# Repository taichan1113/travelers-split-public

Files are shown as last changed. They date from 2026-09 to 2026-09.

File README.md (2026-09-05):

[日本語](#日本語) / [English](#english)

# Travelers Split Public

## English

Public KiCad release bundle for the Travelers Split keyboard hardware.

### Projects

- `split_L_v2/ULP_Keyboard_split_L.kicad_pro`
- `split_R_v2/ULP_Keyboard_split_R.kicad_pro`
- `split_prog/ULP_Keyboard_split_prog.kicad_pro`

### Libraries

Project-local KiCad tables reference the bundled libraries under `libraries/` via `${KIPRJMOD}/../libraries/...`, so the projects can be opened without setting `KICAD_USER_LOCAL`.

### Repository Layout

- `split_L_v2/`: left half KiCad project
- `split_R_v2/`: right half KiCad project
- `split_prog/`: programmer KiCad project
- `libraries/`: symbols, footprints, and 3D models used by the projects

## 日本語

Travelers Split keyboard hardware の公開用 KiCad リリース一式です。

### プロジェクト

- `split_L_v2/ULP_Keyboard_split_L.kicad_pro`
- `split_R_v2/ULP_Keyboard_split_R.kicad_pro`
- `split_prog/ULP_Keyboard_split_prog.kicad_pro`

### ライブラリ

各プロジェクト内の KiCad ライブラリテーブルは、同梱の `libraries/` を `${KIPRJMOD}/../libraries/...` として参照します。そのため、`KICAD_USER_LOCAL` を設定しなくてもプロジェクトを開けます。

### リポジトリ構成

- `split_L_v2/`: 左手側の KiCad プロジェクト
- `split_R_v2/`: 右手側の KiCad プロジェクト
- `split_prog/`: 書き込み器用の KiCad プロジェクト
- `libraries/`: 各プロジェクトで使用するシンボル、フットプリント、3Dモデル

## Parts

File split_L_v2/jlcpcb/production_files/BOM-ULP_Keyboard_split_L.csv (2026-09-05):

Comment | Designator | Footprint | LCSC | Quantity
0.1uF | C3,C5 | C_0603_1608Metric_Pad1.08x0.95mm_HandSolder | C14663 | 2
10uF | C1 | C_0603_1608Metric_Pad1.08x0.95mm_HandSolder | C19702 | 1
1M | R1,R3 | R_0603_1608Metric_Pad0.98x0.95mm_HandSolder | C22935 | 2
D | D00,D01,D02,D03,D04,D05,D10,D11,D12,D13,D14,D15,D20,D21,D22,D23,D24,D25,D30,D34,D35 | Nexperia_CFP3_SOD-123W | C81598 | 21

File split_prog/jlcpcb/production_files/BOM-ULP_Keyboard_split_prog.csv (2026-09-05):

Comment | Designator | Footprint | LCSC | Quantity
1uF X5R | C2,C4 | C_0603_1608Metric_Pad1.08x0.95mm_HandSolder | C19702 | 2
5.1k | R6,R7 | R_0603_1608Metric_Pad0.98x0.95mm_HandSolder | C23186 | 2
TLV75533PDBV | U1 | SOT-23-5 | C404027 | 1
USBLC6-2SC6 | D7 | SOT-23-6 | C7519 | 1

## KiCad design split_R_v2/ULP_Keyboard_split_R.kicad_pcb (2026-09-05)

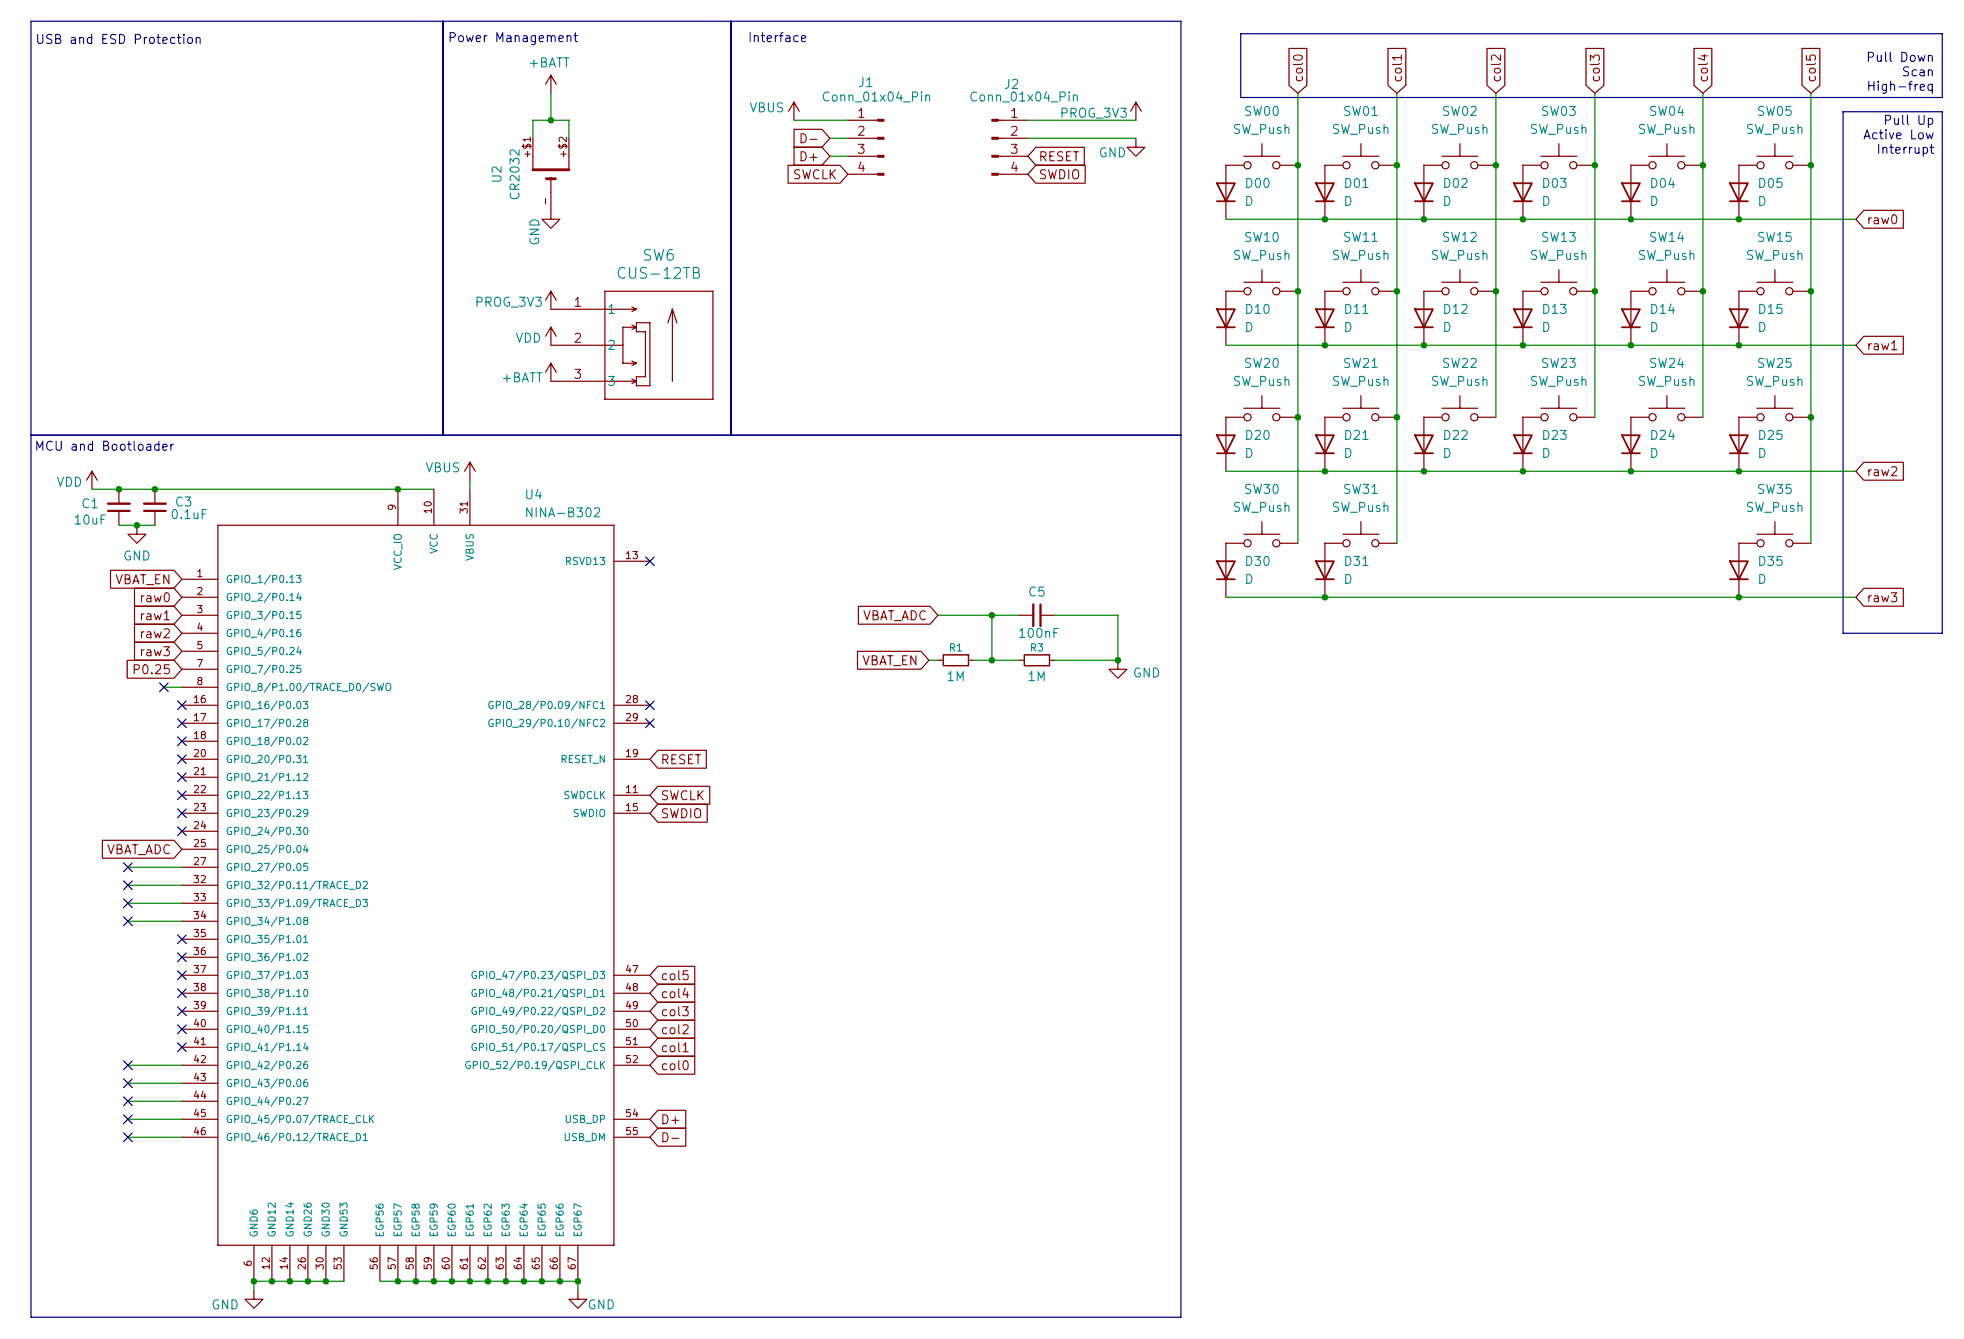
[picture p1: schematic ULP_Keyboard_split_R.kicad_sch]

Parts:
C1: 10uF; C_0603_1608Metric_Pad1.08x0.95mm_HandSolder; LCSC C19702
C3: 0.1uF; C_0603_1608Metric_Pad1.08x0.95mm_HandSolder; LCSC C14663
C5: 100nF; C_0603_1608Metric_Pad1.08x0.95mm_HandSolder; LCSC C14663
D00, D01, D02, D03, D04, D05, D10, D11, D12, D13, D14, D15, D20, D21, D22, D23, D24, D25, D30, D31, D35: D; Nexperia_CFP3_SOD-123W; LCSC C81598
J1, J2: Conn_01x04_Pin; ConnThrough_1x04
R1, R3: 1M; R_0603_1608Metric_Pad0.98x0.95mm_HandSolder; LCSC C22935
SW00, SW01, SW02, SW03, SW04, SW10, SW11, SW12, SW13, SW14, SW20, SW21, SW22, SW23, SW24, SW30, SW31: SW_Push; Kailh_socket_PG1316S_my_SMD
SW05, SW15, SW25, SW35: SW_Push; Kailh_socket_PG1316M_my_SMD
SW6: CUS-12TB; CUS12TB
U2: CR2032; CR2032-SMD-BH67D5
U4: NINA-B302; NINA_302_my; PART_DESCRIPTION Stand-alone Bluetooth low energy module

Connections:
+BATT: SW6.3, U2.+$1, U2.+$2
D+: J1.3, U4.54 (USB_DP)
D-: J1.2, U4.55 (USB_DM)
GND: C1.1, C3.1, C5.1, J2.2, R3.1, U2.-, U4.6 (GND6), U4.12 (GND12), U4.14 (GND14), U4.26 (GND26), U4.30 (GND30), U4.53 (GND53), U4.56 (EGP56), U4.57 (EGP57), U4.58 (EGP58), U4.59 (EGP59), U4.60 (EGP60), U4.61 (EGP61), U4.62 (EGP62), U4.63 (EGP63), U4.64 (EGP64), U4.65 (EGP65), U4.66 (EGP66), U4.67 (EGP67)
unnamed: D00.2 (A), SW00.1
unnamed: D01.2 (A), SW01.1
unnamed: D02.2 (A), SW02.1
unnamed: D03.2 (A), SW03.1
unnamed: D04.2 (A), SW04.1
unnamed: D05.2 (A), SW05.1
unnamed: D10.2 (A), SW10.1
unnamed: D11.2 (A), SW11.1
unnamed: D12.2 (A), SW12.1
unnamed: D13.2 (A), SW13.1
unnamed: D14.2 (A), SW14.1
unnamed: D15.2 (A), SW15.1
unnamed: D20.2 (A), SW20.1
unnamed: D21.2 (A), SW21.1
unnamed: D22.2 (A), SW22.1
unnamed: D23.2 (A), SW23.1
unnamed: D24.2 (A), SW24.1
unnamed: D25.2 (A), SW25.1
unnamed: D30.2 (A), SW30.1
unnamed: D31.2 (A), SW31.1
unnamed: D35.2 (A), SW35.1
P0.25: U4.7 (GPIO_7/P0.25)
PROG_3V3: J2.1, SW6.1
RESET: J2.3, U4.19 (RESET_N)
SWCLK: J1.4, U4.11 (SWDCLK)
SWDIO: J2.4, U4.15 (SWDIO)
VBAT_ADC: C5.2, R1.1, R3.2, U4.25 (GPIO_25/P0.04)
VBAT_EN: R1.2, U4.1 (GPIO_1/P0.13)
VBUS: J1.1, U4.31 (VBUS)
VDD: C1.2, C3.2, SW6.2, U4.9 (VCC_IO), U4.10 (VCC)
col0: SW00.2, SW10.2, SW20.2, SW30.2, U4.52 (GPIO_52/P0.19/QSPI_CLK)
col1: SW01.2, SW11.2, SW21.2, SW31.2, U4.51 (GPIO_51/P0.17/QSPI_CS)
col2: SW02.2, SW12.2, SW22.2, U4.50 (GPIO_50/P0.20/QSPI_D0)
col3: SW03.2, SW13.2, SW23.2, U4.49 (GPIO_49/P0.22/QSPI_D2)
col4: SW04.2, SW14.2, SW24.2, U4.48 (GPIO_48/P0.21/QSPI_D1)
col5: SW05.2, SW15.2, SW25.2, SW35.2, U4.47 (GPIO_47/P0.23/QSPI_D3)
raw0: D00.1 (K), D01.1 (K), D02.1 (K), D03.1 (K), D04.1 (K), D05.1 (K), U4.2 (GPIO_2/P0.14)
raw1: D10.1 (K), D11.1 (K), D12.1 (K), D13.1 (K), D14.1 (K), D15.1 (K), U4.3 (GPIO_3/P0.15)
raw2: D20.1 (K), D21.1 (K), D22.1 (K), D23.1 (K), D24.1 (K), D25.1 (K), U4.4 (GPIO_4/P0.16)
raw3: D30.1 (K), D31.1 (K), D35.1 (K), U4.5 (GPIO_5/P0.24)

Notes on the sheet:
Interface
MCU and Bootloader
Pull Down Scan High-freq
Power Management
Pull Up Active Low Interrupt
USB and ESD Protection

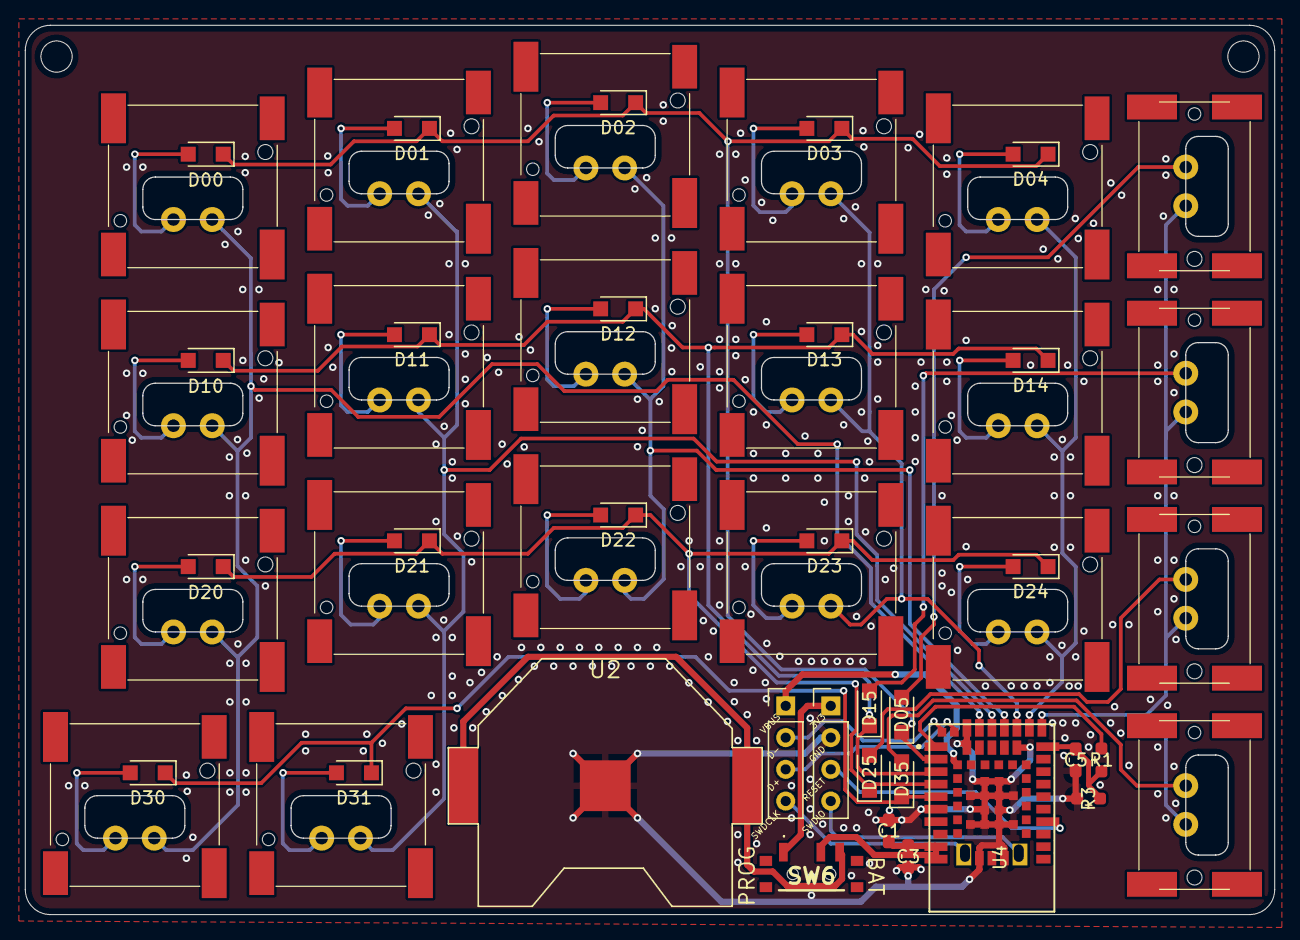
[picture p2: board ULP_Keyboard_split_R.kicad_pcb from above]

Board: 2 copper layers, 100.0 x 71.2 mm, 52 parts (0 on the bottom side), 43 nets.

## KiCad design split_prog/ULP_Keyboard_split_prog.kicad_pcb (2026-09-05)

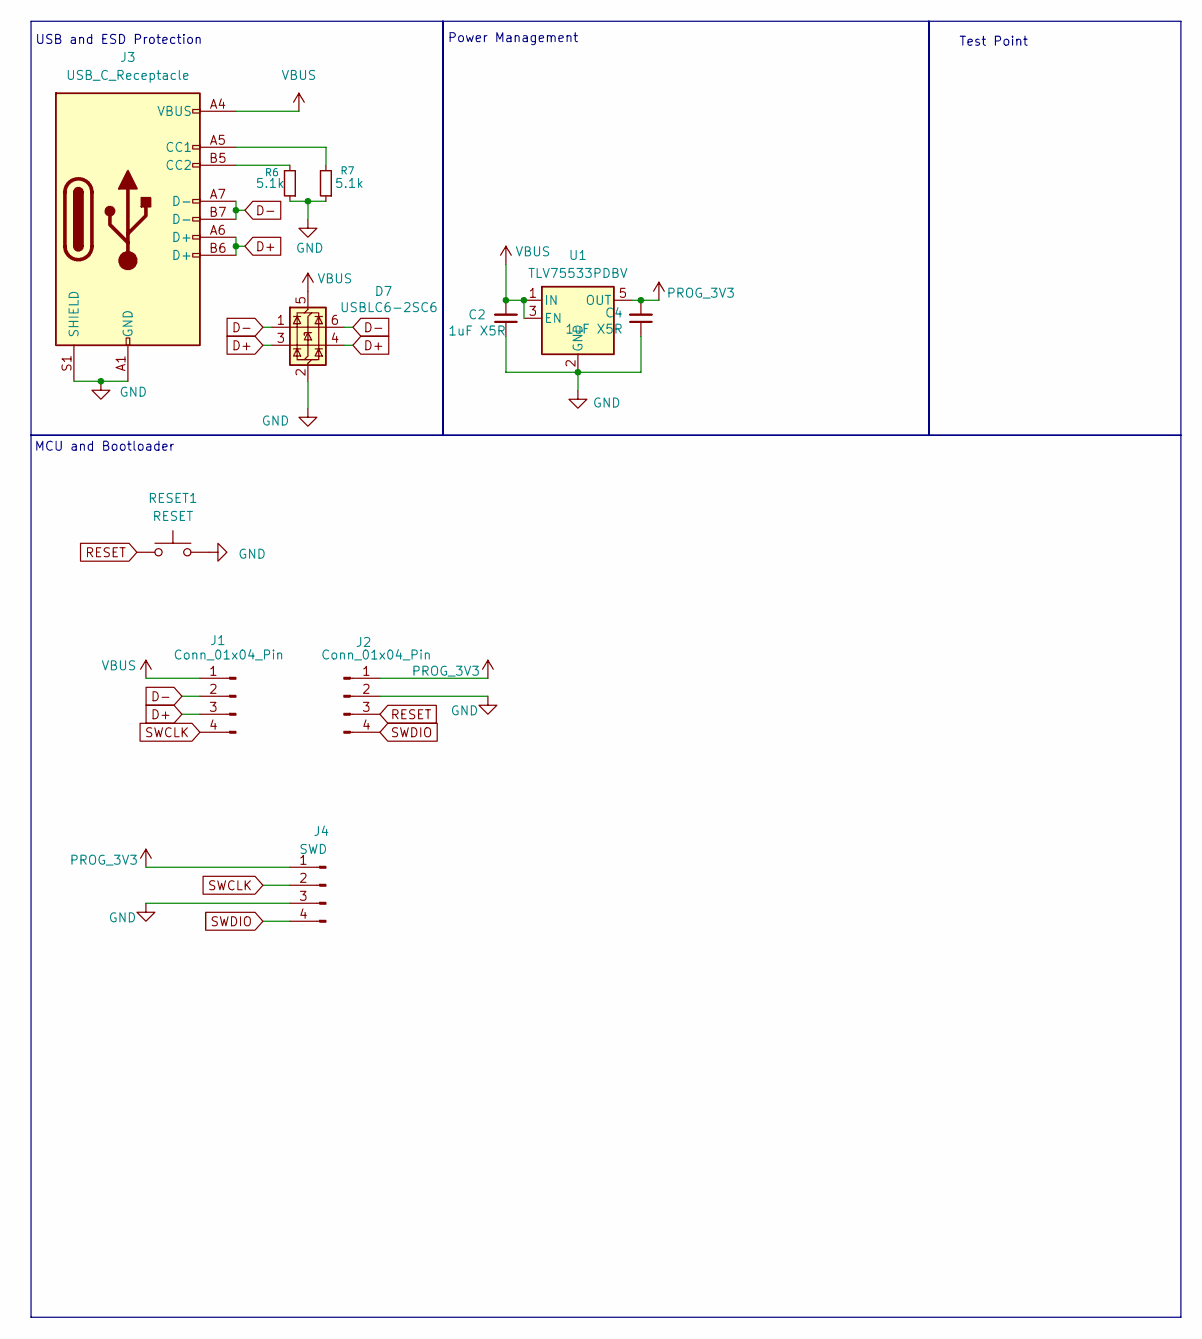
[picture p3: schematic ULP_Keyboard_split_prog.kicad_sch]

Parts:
C2, C4: 1uF X5R; C_0603_1608Metric_Pad1.08x0.95mm_HandSolder; LCSC C19702
D7: USBLC6-2SC6; SOT-23-6; LCSC C7519
J1, J2: Conn_01x04_Pin; ConnThrough_1x04
J3: USB_C_Receptacle; USB_C_Receptacle_HRO_TYPE-C-31-M-12
J4: SWD; JST_SH_BM04B-SRSS-TB_1x04-1MP_P1.00mm_Vertical
R6, R7: 5.1k; R_0603_1608Metric_Pad0.98x0.95mm_HandSolder; LCSC C23186
RESET1: RESET; SW_SPST_TL3342
U1: TLV75533PDBV; SOT-23-5; LCSC C404027

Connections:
D+: D7.3 (I/O2), D7.4 (I/O2), J1.3, J3.A6 (D+), J3.B6 (D+)
D-: D7.1 (I/O1), D7.6 (I/O1), J1.2, J3.A7 (D-), J3.B7 (D-)
GND: C2.1, C4.1, D7.2 (GND), J2.2, J3.A1 (GND), J3.A12 (GND), J3.B1 (GND), J3.B12 (GND), J3.S1 (SHIELD), J4.3, R6.1, R7.1, RESET1.2, U1.2 (GND)
unnamed: J3.A5 (CC1), R7.2
unnamed: J3.B5 (CC2), R6.2
PROG_3V3: C4.2, J2.1, J4.1, U1.5 (OUT)
RESET: J2.3, RESET1.1
SWCLK: J1.4, J4.2
SWDIO: J2.4, J4.4
VBUS: C2.2, D7.5 (VBUS), J1.1, J3.A4 (VBUS), J3.A9 (VBUS), J3.B4 (VBUS), J3.B9 (VBUS), U1.1 (IN), U1.3 (EN)

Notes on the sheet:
Test Point
MCU and Bootloader
Power Management
USB and ESD Protection

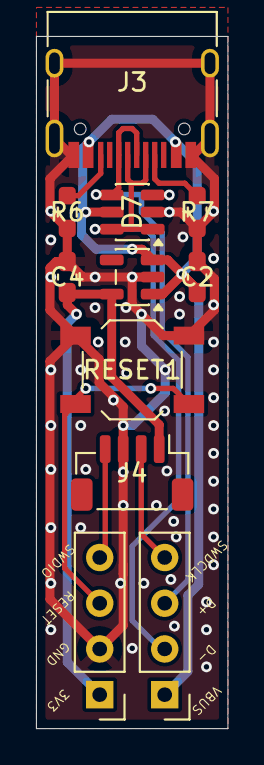
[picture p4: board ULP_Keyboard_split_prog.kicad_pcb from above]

Board: 2 copper layers, 10.6 x 38.5 mm, 11 parts (0 on the bottom side), 10 nets.

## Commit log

2026-09-05 Initial public KiCad release
    [BOM-ULP_Keyboard_split_L.csv, BOM-ULP_Keyboard_split_R.csv, BOM-ULP_Keyboard_split_prog.csv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]
2026-09-05 Save current public repo state
